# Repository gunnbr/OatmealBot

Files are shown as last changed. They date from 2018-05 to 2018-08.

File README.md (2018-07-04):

# OatmealBot
OatmealBot is a robot built on a circular platform using 3 [omni wheels](https://en.wikipedia.org/wiki/Omni_wheel) and
controlled using a PS3 controller. It's named OatmealBot because it was
originally designed so the control hardware could be hidden under a
cylindrical box of oatmeal.

## Features
This OatmealBot controller is built on top of the
[Adafruit Motor Hat](http://adafru.it/2348). This board provides the
following features on top of that:
* Powers the Hat and the Pi from a [Pololu 5V regulator](https://www.pololu.com/product/2858)
* Plug for 4
[Pololu motors with quadrature encoder](https://www.pololu.com/product/3240)
* Plugs for 3 servos
* 2 high power outputs
* Plug for [SPI OLED display](http://adafru.ti/938)
* 2 LED (status & error)
* Plug for
[FTDI TTL serial to USB adapter](http://www.ftdichip.com/Support/Documents/DataSheets/Cables/DS_TTL-232R_CABLES.pdf)

## History
This was initially envisioned using a SAMD21 controller so the motor
encoders could be read by hardware counters. However, I couldn't find
a good Bluetooth driver that worked. Although I found some existing
drivers that could be ported, I realized I could just as well get
a Raspberry Pi Zero W with built-in Bluetooth and a motor hat and
see how well it works without reading the encoders. Turns out it
worked fairly well, so I kept working down this path.

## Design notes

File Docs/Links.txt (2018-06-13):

http://www.societyofrobots.com/robot_omni_wheel.shtml

http://files.andymark.com/2008CON-Omni-Baker-McKenzie.pdf

http://basicrobot.blogspot.nl/2006/08/how-to-control-omni-direction-wheel.html

http://robotics.stackexchange.com/questions/7829/how-to-program-three-wheel-omni

http://stackoverflow.com/questions/3748037/how-to-control-a-kiwi-drive-robot

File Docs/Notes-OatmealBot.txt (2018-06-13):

To use a BT USB dongle with the Arduino Zero/Feather M0/SAMD21:
https://github.com/bluekitchen/btstack
Which is from:
http://bluekitchen-gmbh.com/
But it doesn't look like USB is very much supported. But maybe it is--it is referenced a few times.

Maybe port https://www.circuitsathome.com/category/mcu/arduino/usb-shield/ to the M0?
The latest version does support some native USB: https://github.com/felis/UHS30

Bluetooth spec:
https://www.bluetooth.com/specifications/bluetooth-core-specification

Atmel Studio contains an ASF example of a host vendor USB device. Looks like this is a template
for how a Bluetooth HCI class driver can be written.
Documentation about it is here: http://www.atmel.com/Images/Atmel-42336-ASF-USB-Stack-Manual_ApplicationNote_AT09331.pdf

Or port this, which is already for an embedded system and PS3 controller:
http://www.fourwalledcubicle.com/ExplorerBot.php
https://github.com/abcminiuser/explorerbot/tree/master/Code

New plan:
Run it from the Pi Zero.

From https://medium.com/home-wireless/headless-streaming-video-with-the-raspberry-pi-zero-w-and-raspberry-pi-camera-38bef1968e1
and https://github.com/cncjs/cncjs/wiki/Setup-Guide:-Raspberry-Pi-%7C-MJPEG-Streamer-Install-&-Setup-&-FFMpeg-Recording

To stream video from the Pi: 
mjpg_streamer -i "input_raspicam.so -x 1920 -y 1080" -o 'output_http.so -w ./www'

Then in a browser, go to:
http://10.0.0.37:8080/?action=stream

Article with the formulas:
https://stackoverflow.com/questions/3748037/how-to-control-a-kiwi-drive-robot

Gears in my kit: 2.00 mm inner diameter
Tower Pro micro server: 
	Inner diameter between 1.5 and 1.75 mm (designed for a screw)
	Outer diameter: 2.85 mm

Pi Adapter/control board: (22 total GPIO pins)
	Power in (easy to detach connector?)
	Voltage converter to 5V pin on Pi expansion header
	Headers to plug in the 4 motors with an easy way to connect them to the motor driver board and with A and B from the rotary encoder (8 GPIO lines)
	Headers for 4 servos (4 GPIO lines)
	SPI header for OLED display (5 GPIO)
	SPI header for other things (1 additional GPIO)
	LED indicators: (2 GPIO)
		1 neutral color indicate Bluetooth connection status
		1 red for error conditions
	
Adafruit Feature board that's similar

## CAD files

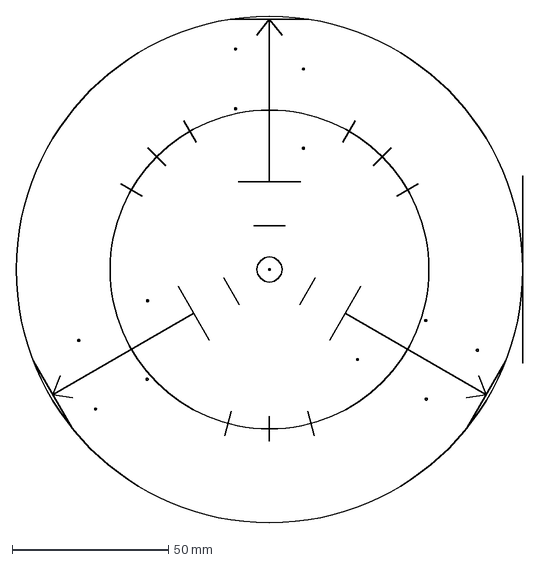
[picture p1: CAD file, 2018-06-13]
Mechanical/OutmealBotTemplate2.dxf
161.9 x 161.9 mm

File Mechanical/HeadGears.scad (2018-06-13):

//////////////////////////////////////////////////////////////////////////////////////////////
// Public Domain Parametric Involute Spur Gear (and involute helical gear and involute rack)
// version 1.1
// by Leemon Baird, 2011, Leemon@Leemon.com
//http://www.thingiverse.com/thing:5505
//
// This file is public domain.  Use it for any purpose, including commercial
// applications.  Attribution would be nice, but is not required.  There is
// no warranty of any kind, including its correctness, usefulness, or safety.
// 
// This is parameterized involute spur (or helical) gear.  It is much simpler and less powerful than
// others on Thingiverse.  But it is public domain.  I implemented it from scratch from the 
// descriptions and equations on Wikipedia and the web, using Mathematica for calculations and testing,
// and I now release it into the public domain.
//
//		http://en.wikipedia.org/wiki/Involute_gear
//		http://en.wikipedia.org/wiki/Gear
//		http://en.wikipedia.org/wiki/List_of_gear_nomenclature
//		http://gtrebaol.free.fr/doc/catia/spur_gear.html
//		http://www.cs.cmu.edu/~rapidproto/mechanisms/chpt7.html
//
// The module gear() gives an involute spur gear, with reasonable defaults for all the parameters.
// Normally, you should just choose the first 4 parameters, and let the rest be default values.
// The module gear() gives a gear in the XY plane, centered on the origin, with one tooth centered on
// the positive Y axis.  The various functions below it take the same parameters, and return various
// measurements for the gear.  The most important is pitch_radius, which tells how far apart to space
// gears that are meshing, and adendum_radius, which gives the size of the region filled by the gear.
// A gear has a "pitch circle", which is an invisible circle that cuts through the middle of each
// tooth (though not the exact center). In order for two gears to mesh, their pitch circles should 
// just touch.  So the distance between their centers should be pitch_radius() for one, plus pitch_radius() 
// for the other, which gives the radii of their pitch circles.
//
// In order for two gears to mesh, they must have the same mm_per_tooth and pressure_angle parameters.  
// mm_per_tooth gives the number of millimeters of arc around the pitch circle covered by one tooth and one
// space between teeth.  The pitch angle controls how flat or bulged the sides of the teeth are.  Common
// values include 14.5 degrees and 20 degrees, and occasionally 25.  Though I've seen 28 recommended for
// plastic gears. Larger numbers bulge out more, giving stronger teeth, so 28 degrees is the default here.
//
// The ratio of number_of_teeth for two meshing gears gives how many times one will make a full 
// revolution when the the other makes one full revolution.  If the two numbers are coprime (i.e. 
// are not both divisible by the same number greater than 1), then every tooth on one gear
// will meet every tooth on the other, for more even wear.  So coprime numbers of teeth are good.
//
// The module rack() gives a rack, which is a bar with teeth.  A rack can mesh with any
// gear that has the same mm_per_tooth and pressure_angle.
//
// Some terminology: 
// The outline of a gear is a smooth circle (the "pitch circle") which has mountains and valleys
// added so it is toothed.  So there is an inner circle (the "root circle") that touches the 
// base of all the teeth, an outer circle that touches the tips of all the teeth,
// and the invisible pitch circle in between them.  There is also a "base circle", which can be smaller than
// all three of the others, which controls the shape of the teeth.  The side of each tooth lies on the path 
// that the end of a string would follow if it were wrapped tightly around the base circle, then slowly unwound.  
// That shape is an "involute", which gives this type of gear its name.
//
//////////////////////////////////////////////////////////////////////////////////////////////

//An involute spur gear, with reasonable defaults for all the parameters.
//Normally, you should just choose the first 4 parameters, and let the rest be default values.
//Meshing gears must match in mm_per_tooth, pressure_angle, and twist,
//and be separated by the sum of their pitch radii, which can be found with pitch_radius().
module gear (
	mm_per_tooth    = 3,    //this is the "circular pitch", the circumference of the pitch circle divided by the number of teeth
	number_of_teeth = 11,   //total number of teeth around the entire perimeter
	thickness       = 6,    //thickness of gear in mm
	hole_diameter   = 3,    //diameter of the hole in the center, in mm
	twist           = 0,    //teeth rotate this many degrees from bottom of gear to top.  360 makes the gear a screw with each thread going around once
	teeth_to_hide   = 0,    //number of teeth to delete to make this only a fraction of a circle
	pressure_angle  = 28,   //Controls how straight or bulged the tooth sides are. In degrees.
	clearance       = 0.0,  //gap between top of a tooth on one gear and bottom of valley on a meshing gear (in millimeters)
	backlash        = 0.0   //gap between two meshing teeth, in the direction along the circumference of the pitch circle
) {
	assign(pi = 3.1415926)
	assign(p  = mm_per_tooth * number_of_teeth / pi / 2)  //radius of pitch circle
	assign(c  = p + mm_per_tooth / pi - clearance)        //radius of outer circle
	assign(b  = p*cos(pressure_angle))                    //radius of base circle
	assign(r  = p-(c-p)-clearance)                        //radius of root circle
	assign(t  = mm_per_tooth/2-backlash/2)                //tooth thickness at pitch circle
	assign(k  = -iang(b, p) - t/2/p/pi*180) {             //angle to where involute meets base circle on each side of tooth
		difference() {
			for (i = [0:number_of_teeth-teeth_to_hide-1] )
				rotate([0,0,i*360/number_of_teeth])
					linear_extrude(height = thickness, center = true, convexity = 10, twist = twist)
						polygon(
							points=[
								[0, -hole_diameter/10],
								polar(r, -181/number_of_teeth),
								polar(r, r<b ? k : -180/number_of_teeth),
								q7(0/5,r,b,c,k, 1),q7(1/5,r,b,c,k, 1),q7(2/5,r,b,c,k, 1),q7(3/5,r,b,c,k, 1),q7(4/5,r,b,c,k, 1),q7(5/5,r,b,c,k, 1),
								q7(5/5,r,b,c,k,-1),q7(4/5,r,b,c,k,-1),q7(3/5,r,b,c,k,-1),q7(2/5,r,b,c,k,-1),q7(1/5,r,b,c,k,-1),q7(0/5,r,b,c,k,-1),
								polar(r, r<b ? -k : 180/number_of_teeth),
								polar(r, 181/number_of_teeth)
							],
 							paths=[[0,1,2,3,4,5,6,7,8,9,10,11,12,13,14,15,16]]
						);
			cylinder(h=2*thickness+1, r=hole_diameter/2, center=true, $fn=20);
		}
	}
};	
//these 4 functions are used by gear
function polar(r,theta)   = r*[sin(theta), cos(theta)];                            //convert polar to cartesian coordinates
function iang(r1,r2)      = sqrt((r2/r1)*(r2/r1) - 1)/3.1415926*180 - acos(r1/r2); //unwind a string this many degrees to go from radius r1 to radius r2
function q7(f,r,b,r2,t,s) = q6(b,s,t,(1-f)*max(b,r)+f*r2);                         //radius a fraction f up the curved side of the tooth 
function q6(b,s,t,d)      = polar(d,s*(iang(b,d)+t));                              //point at radius d on the involute curve

//a rack, which is a straight line with teeth (the same as a segment from a giant gear with a huge number of teeth).
//The "pitch circle" is a line along the X axis.
module rack (
	mm_per_tooth    = 3,    //this is the "circular pitch", the circumference of the pitch circle divided by the number of teeth
	number_of_teeth = 11,   //total number of teeth along the rack
	thickness       = 6,    //thickness of rack in mm (affects each tooth)
	height          = 120,   //height of rack in mm, from tooth top to far side of rack.
	pressure_angle  = 28,   //Controls how straight or bulged the tooth sides are. In degrees.
	backlash        = 0.0   //gap between two meshing teeth, in the direction along the circumference of the pitch circle
) {
	assign(pi = 3.1415926)
	assign(a = mm_per_tooth / pi) //addendum
	assign(t = a*cos(pressure_angle)-1)         //tooth side is tilted so top/bottom corners move this amount
		for (i = [0:number_of_teeth-1] )
			translate([i*mm_per_tooth,0,0])
				linear_extrude(height = thickness, center = true, convexity = 10)
					polygon(
						points=[
							[-mm_per_tooth * 3/4,                 a-height],
							[-mm_per_tooth * 3/4 - backlash,     -a],
							[-mm_per_tooth * 1/4 + backlash - t, -a],
							[-mm_per_tooth * 1/4 + backlash + t,  a],
							[ mm_per_tooth * 1/4 - backlash - t,  a],
							[ mm_per_tooth * 1/4 - backlash + t, -a],
							[ mm_per_tooth * 3/4 + backlash,     -a],
							[ mm_per_tooth * 3/4,                 a-height],
						],
						paths=[[0,1,2,3,4,5,6,7]]
					);
};
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

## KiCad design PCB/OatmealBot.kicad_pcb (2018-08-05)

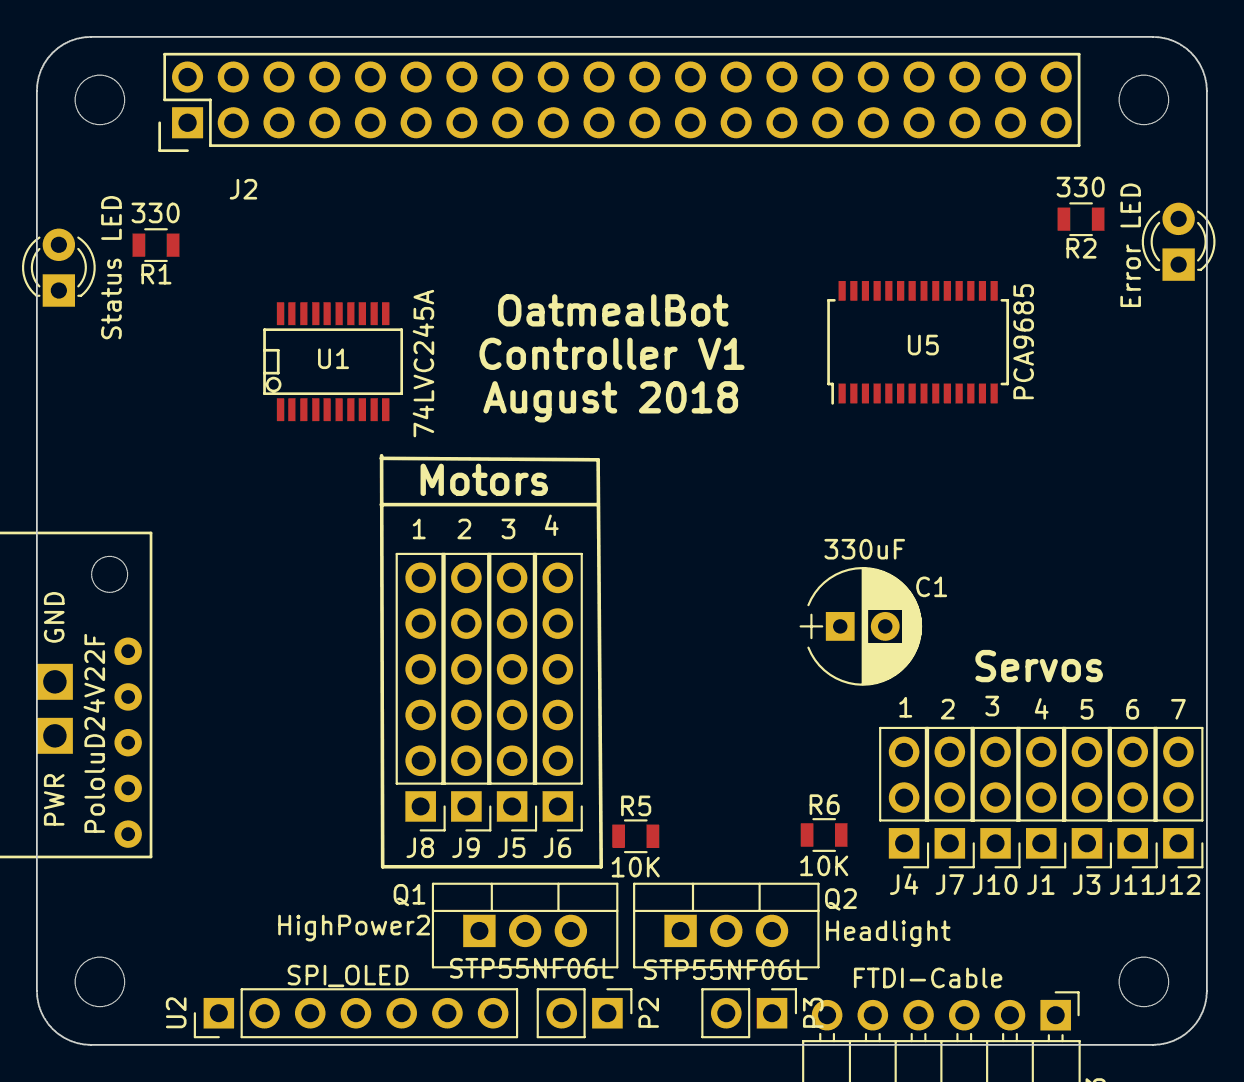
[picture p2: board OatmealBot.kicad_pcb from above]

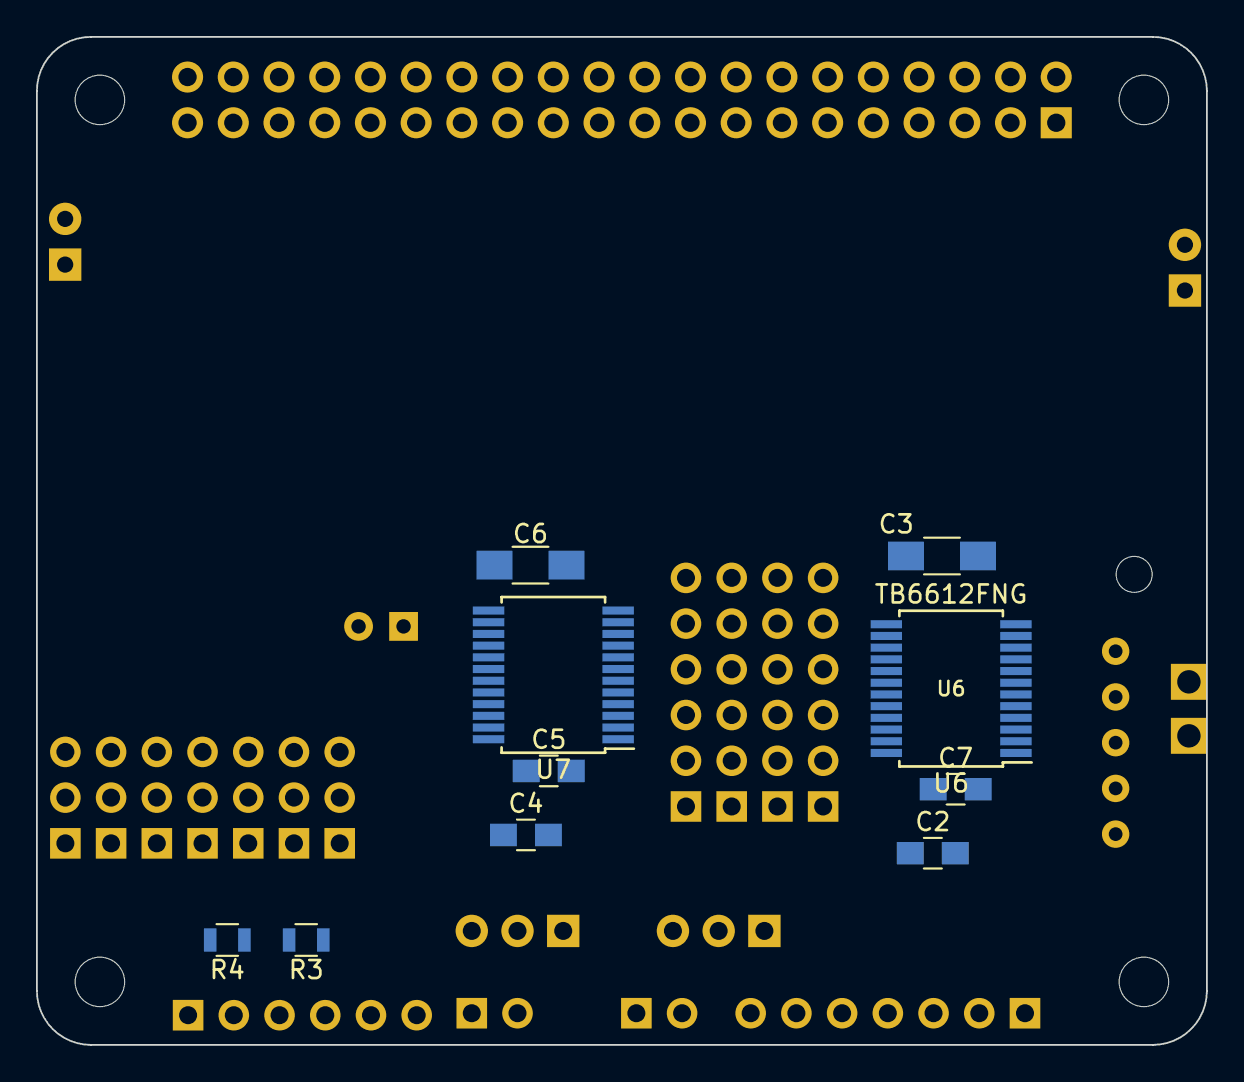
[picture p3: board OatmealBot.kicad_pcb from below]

Board: 2 copper layers, 65.0 x 56.0 mm, 39 parts (10 on the bottom side), 65 nets, no tracks yet.

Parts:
C1: 330uF; CP_Radial_D6.3mm_P2.50mm
C2, C4: 10uF; C_0805_HandSoldering
C3, C6: 47uF; C_1206_HandSoldering
C5, C7: 0.1uF; C_0805_HandSoldering
D1: Status LED; LED_D3.0mm
D2: Error LED; LED_D3.0mm
J1: 4; Pin_Header_Straight_1x03_Pitch2.54mm
J2: RPi_GPIO; Pin_Header_Straight_2x20
J3: 5; Pin_Header_Straight_1x03_Pitch2.54mm
J4: 1; Pin_Header_Straight_1x03_Pitch2.54mm
J5: 3; Pin_Header_Straight_1x06_Pitch2.54mm
J6: 4; Pin_Header_Straight_1x06_Pitch2.54mm
J7: 2; Pin_Header_Straight_1x03_Pitch2.54mm
J8: 1; Pin_Header_Straight_1x06_Pitch2.54mm
J9: 2; Pin_Header_Straight_1x06_Pitch2.54mm
J10: 3; Pin_Header_Straight_1x03_Pitch2.54mm
J11: 6; Pin_Header_Straight_1x03_Pitch2.54mm
J12: 7; Pin_Header_Straight_1x03_Pitch2.54mm
P1: Motor Hat Power; Power_Connector_Soldered
P2: HighPower2; Pin_Header_Straight_1x02_Pitch2.54mm
P3: Headlight; Pin_Header_Straight_1x02_Pitch2.54mm
Q1, Q2: STP55NF06L; TO-220-3_Vertical
R1, R2: 330; R_0805
R3, R4: R; R_0805
R5, R6: 10K; R_0805
U1: 74LVC245A; SSOP-20
U2: SPI_OLED; Socket_Strip_Straight_1x07_Pitch2.54mm
U3: FTDI-Cable; Pin_Header_Angled_1x06_Pitch2.54mm
U4: PololuD24V22F
U5: PCA9685; TSSOP-28_4.4x9.7mm_Pitch0.65mm
U6, U7: TB6612FNG; SSOP-24_5.3x8.2mm_Pitch0.65mm

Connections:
+3V3: C2.1, C4.1, C5.1, C7.1, J2.1, J2.17, U1.1, U1.20, U2.2, U5.24, U5.28, U6.19, U6.20, U7.19, U7.20
+5V: C1.1, J1.2, J2.2, J2.4, J3.2, J4.2, J5.4, J6.4, J7.2, J8.4, J9.4, J10.2, J11.2, J12.2, U4.5
+12V: C3.1, C6.1, P1.2, U4.3, U6.13, U6.14, U6.24, U7.13, U7.14, U7.24
/MotorController/Motor1+: J8.1, U6.1, U6.2
/MotorController/Motor1-: J8.2, U6.5, U6.6
/MotorController/Motor2+: J9.1, U6.7, U6.8
/MotorController/Motor2-: J9.2, U6.11, U6.12
/MotorController/Motor3+: J5.1, U7.1, U7.2
/MotorController/Motor3-: J5.2, U7.5, U7.6
/MotorController/Motor4+: J6.1, U7.7, U7.8
/MotorController/Motor4-: J6.2, U7.11, U7.12
ENC1A: J2.40, U1.17
ENC1B: J2.38, U1.18
ENC2A: J2.36, U1.15
ENC2B: J2.37, U1.16
ENC3A: J2.33, U1.13
ENC3B: J2.35, U1.14
ENC4A: J2.31, U1.11
ENC4B: J2.29, U1.12
GND: C1.2, C2.2, C3.2, C4.2, C5.2, C6.2, C7.2, D1.1, D2.1, J1.1, J2.6, J2.9, J2.14, J2.20, J2.25, J2.30, J2.34, J2.39, J3.1, J4.1, J5.3, J6.3, J7.1, J8.3, J9.3, J10.1, J11.1, J12.1, P1.1, P2.1, P3.1, Q1.3, Q2.3, R4.2, R5.2, R6.2, U1.10, U1.19, U2.1, U3.1, U4.4, U5.1, U5.2, U5.3, U5.4, U5.5, U5.14, U5.23, U5.25, U6.3, U6.4, U6.9, U6.10, U6.18, U7.3, U7.4, U7.9, U7.10, U7.18
Headlight: J2.7, Q2.1, R6.1
HighPower2: J2.13, Q1.1, R5.1
MOSI: J2.19, U2.4
unnamed: D1.2, R1.2
unnamed: D2.2, R2.1
unnamed: J2.15, R1.1
unnamed: J2.16, R2.2
unnamed: J5.5, U1.7
unnamed: J5.6, U1.6
unnamed: J6.5, U1.9
unnamed: J6.6, U1.8
unnamed: J8.5, U1.3
unnamed: J8.6, U1.2
unnamed: J9.5, U1.5
unnamed: J9.6, U1.4
unnamed: P2.2, Q1.2
unnamed: P3.2, Q2.2
unnamed: R3.1, U3.4
unnamed: U5.8, U6.23
unnamed: U5.9, U6.22
unnamed: U5.10, U6.21
unnamed: U5.11, U6.17
unnamed: U5.12, U6.16
unnamed: U5.13, U6.15
unnamed: U5.15, U7.23
unnamed: U5.16, U7.22
unnamed: U5.17, U7.21
unnamed: U5.18, U7.17
unnamed: U5.19, U7.16
unnamed: U5.20, U7.15
OLED_CS: J2.24, U2.7
OLED_DC: J2.22, U2.6
OLED_RESET: J2.18, U2.5
PI_RXD: J2.10, R3.2, R4.1
PI_TXD: J2.8, U3.5
SCL: J2.5, U5.26
SCLK: J2.23, U2.3
SDA: J2.3, U5.27
Servo1: J2.32, J4.3
Servo2: J2.12, J7.3
Servo3: J2.11, J10.3
Servo4: J1.3, U5.6
Servo5: J3.3, U5.7
Servo6: J11.3, U5.21
Servo7: J12.3, U5.22

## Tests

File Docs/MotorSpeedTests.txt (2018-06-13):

100 ms per line

TCNT: 20
TCNT: 22
TCNT: 22
TCNT: 21
TCNT: 22
TCNT: 22
TCNT: 21
TCNT: 22
TCNT: 22
TCNT: 21
TCNT: 22
TCNT: 22
TCNT: 21
TCNT: 22
TCNT: 22
TCNT: 21
TCNT: 21
TCNT: 22
TCNT: 22
TCNT: 21
TCNT: 22
TCNT: 22
TCNT: 22
TCNT: 21
TCNT: 22
TCNT: 22
TCNT: 21
TCNT: 22
TCNT: 22
TCNT: 21
TCNT: 22
TCNT: 22
TCNT: 21
Speed: 255
TCNT: 46
TCNT: 102
TCNT: 106
TCNT: 107
TCNT: 106
TCNT: 107
TCNT: 107
TCNT: 106
TCNT: 107
TCNT: 107
TCNT: 107
TCNT: 107
TCNT: 107
TCNT: 107
TCNT: 107
TCNT: 107
TCNT: 106
TCNT: 107
TCNT: 107
TCNT: 107
Speed: 10
TCNT: 85
TCNT: 7
TCNT: 1
TCNT: 3
TCNT: 1
TCNT: 2
TCNT: 1
TCNT: 2
TCNT: 3
TCNT: 2
TCNT: 3
TCNT: 2
TCNT: 3
TCNT: 2
TCNT: 3
TCNT: 2
TCNT: 2
TCNT: 3
TCNT: 2
TCNT: 3
TCNT: 2
Speed: 255
TCNT: 69
TCNT: 105
TCNT: 107
TCNT: 107
TCNT: 107
TCNT: 107
TCNT: 107
TCNT: 107
TCNT: 107
TCNT: 107
TCNT: 107
TCNT: 107
TCNT: 107
TCNT: 108
TCNT: 107
TCNT: 107
TCNT: 107
TCNT: 107
TCNT: 107
TCNT: 107
Speed: 10
TCNT: 106
TCNT: 22
TCNT: 2
TCNT: 2
TCNT: 2
TCNT: 2
TCNT: 1
TCNT: 1
TCNT: 3
TCNT: 3
TCNT: 2
TCNT: 3
TCNT: 2
TCNT: 3
TCNT: 2
TCNT: 3
TCNT: 2
Speed: 128
TCNT: 38
TCNT: 53
TCNT: 53
TCNT: 53
TCNT: 53
TCNT: 53
TCNT: 53
TCNT: 52
TCNT: 53
TCNT: 53
TCNT: 53
TCNT: 53
TCNT: 53
Speed: 10
TCNT: 34
TCNT: 3
TCNT: 3
TCNT: 3
TCNT: 2
TCNT: 2
TCNT: 3
TCNT: 3
TCNT: 2
TCNT: 3
TCNT: 2
TCNT: 3
TCNT: 2
TCNT: 3
TCNT: 3
TCNT: 2
Speed: 128
TCNT: 33
TCNT: 52
TCNT: 53
TCNT: 53
TCNT: 53
TCNT: 53
TCNT: 53
TCNT: 53
TCNT: 53
TCNT: 53
TCNT: 52
TCNT: 53
TCNT: 53
TCNT: 53
TCNT: 53
TCNT: 53
TCNT: 53
TCNT: 53
Speed: 10
TCNT: 22
TCNT: 2
TCNT: 3
TCNT: 2
TCNT: 3
TCNT: 2
TCNT: 2
TCNT: 3
TCNT: 2
TCNT: 3
TCNT: 2
TCNT: 3
TCNT: 2
Speed: 128
TCNT: 28
TCNT: 53
TCNT: 53
TCNT: 53
TCNT: 53
TCNT: 53
TCNT: 53
TCNT: 52
TCNT: 53
TCNT: 53
TCNT: 53
TCNT: 53
TCNT: 53
TCNT: 53
TCNT: 53
Speed: 255
TCNT: 73
TCNT: 105
TCNT: 107
TCNT: 107
TCNT: 106
TCNT: 108
TCNT: 107
TCNT: 107
TCNT: 107
TCNT: 107
TCNT: 108
TCNT: 107
TCNT: 107
TCNT: 107
TCNT: 107
Speed: 128
TCNT: 100
TCNT: 59
TCNT: 49
TCNT: 43
TCNT: 38
TCNT: 32
TCNT: 37
TCNT: 52
TCNT: 53
TCNT: 53
TCNT: 53
TCNT: 53
TCNT: 53
TCNT: 53
TCNT: 53
TCNT: 54
TCNT: 52
TCNT: 53
TCNT: 53
TCNT: 53
TCNT: 53
TCNT: 54
TCNT: 53
Speed: 255
TCNT: 55
TCNT: 98
TCNT: 107
TCNT: 107
TCNT: 107
TCNT: 108
TCNT: 107
TCNT: 107
TCNT: 108
TCNT: 107
TCNT: 107
TCNT: 108
TCNT: 107
TCNT: 107
Speed: 128
TCNT: 99
TCNT: 58
TCNT: 49
TCNT: 43
TCNT: 37
TCNT: 33
TCNT: 37
TCNT: 53
TCNT: 53
TCNT: 53
TCNT: 53
TCNT: 54
TCNT: 53
TCNT: 53
TCNT: 53
TCNT: 53
TCNT: 53
TCNT: 53
TCNT: 54
TCNT: 53
TCNT: 53
Speed: 255
TCNT: 85
TCNT: 106
TCNT: 108
TCNT: 107
TCNT: 107
TCNT: 108
TCNT: 107
TCNT: 108
TCNT: 107
TCNT: 108
Speed: 128
TCNT: 92
TCNT: 56
TCNT: 48
TCNT: 42
TCNT: 37 <-- Strange dip below the target value when going from full to half speed
TCNT: 32
TCNT: 42
TCNT: 53 <-- 800 ms until target speed
TCNT: 53
TCNT: 53
TCNT: 53
TCNT: 53
TCNT: 53
TCNT: 54
TCNT: 53
TCNT: 53
TCNT: 53
TCNT: 54
TCNT: 53
TCNT: 53
TCNT: 53
TCNT: 53
TCNT: 53
TCNT: 53
TCNT: 54
TCNT: 53
TCNT: 53
TCNT: 53
TCNT: 53
TCNT: 53
TCNT: 54
TCNT: 53
TCNT: 53
TCNT: 53
TCNT: 53
TCNT: 53
TCNT: 53
TCNT: 54
TCNT: 53
TCNT: 53
TCNT: 53
TCNT: 53
TCNT: 53
TCNT: 54
TCNT: 53
TCNT: 53
TCNT: 53
TCNT: 53
T

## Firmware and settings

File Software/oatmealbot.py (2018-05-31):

#!/usr/bin/python

import os, struct, array, time, sys
import threading
from fcntl import ioctl
import pigpio
import atexit
import math
import translatemotoroutputs
from Adafruit_MotorHAT import Adafruit_MotorHAT, Adafruit_DCMotor

debug = False

pi = pigpio.pi()

joyfn = '/dev/input/js0'
jsdev = -1
LED_PIN = 26

# We'll store the button states here.
axis_states = {}
button_states = {}

# Create the MotorHat object using default settings,
# no changes to I2C address or frequency
mh = Adafruit_MotorHAT(addr=0x60)

exiting = False

def emergencyShutdown():
    global exiting
    
    exiting = True
    # Full stop on all the motors
    mh.getMotor(1).run(Adafruit_MotorHAT.RELEASE)
    mh.getMotor(2).run(Adafruit_MotorHAT.RELEASE)
    mh.getMotor(3).run(Adafruit_MotorHAT.RELEASE)
    mh.getMotor(4).run(Adafruit_MotorHAT.RELEASE)

    pi.wave_tx_stop()
    error_flash = []
    error_flash.append(pigpio.pulse(1<<LED_PIN,    0, 100000))
    error_flash.append(pigpio.pulse(0,    1<<LED_PIN, 100000))
    error_flash.append(pigpio.pulse(1<<LED_PIN,    0, 100000))
    error_flash.append(pigpio.pulse(0,    1<<LED_PIN, 100000))
    error_flash.append(pigpio.pulse(1<<LED_PIN,    0, 100000))
    error_flash.append(pigpio.pulse(0,    1<<LED_PIN, 1000000))
    pi.wave_clear() # clear any existing waveforms
    pi.wave_add_generic(error_flash)
    errorFlash = pi.wave_create() # create and save id
    pi.wave_send_repeat(errorFlash)
    
atexit.register(emergencyShutdown)

# These constants were borrowed from linux/input.h
axis_names = {
    0x00 : 'x',
    0x01 : 'y',
    0x02 : 'z',
    0x03 : 'rx',
    0x04 : 'ry',
    0x05 : 'rz',
    0x06 : 'trottle',
    0x07 : 'rudder',
    0x08 : 'wheel',
    0x09 : 'gas',
    0x0a : 'brake',
    0x10 : 'hat0x',
    0x11 : 'hat0y',
    0x12 : 'hat1x',
    0x13 : 'hat1y',
    0x14 : 'hat2x',
    0x15 : 'hat2y',
    0x16 : 'hat3x',
    0x17 : 'hat3y',
    0x18 : 'pressure',
    0x19 : 'distance',
    0x1a : 'tilt_x',
    0x1b : 'tilt_y',
    0x1c : 'tool_width',
    0x20 : 'volume',
    0x28 : 'misc',
    0x2c : 'dpad up',  # ps3
    0x2d : 'dpad right',  # ps3
    0x2e : 'dpad down',  # ps3
    0x2f : 'dpad left',  # ps3
    0x30 : 'left trigger',  # ps3
    0x31 : 'right trigger', # ps3
    0x32 : 'left shoulder',  # ps3
    0x33 : 'right shoulder',  # ps3
    0x34 : 'triangle',  # ps3
    0x35 : 'circle',   # ps3
    0x36 : 'x',   # ps3
    0x37 : 'square',   # ps3
}

button_names = {
    0x120 : 'menu', # ps3
    0x121 : 'left thumb', # ps3
    0x122 : 'right thumb', # ps3
    0x123 : 'start', # ps3
    0x124 : 'dpad up', # ps3
    0x125 : 'dpad right', # ps3
    0x126 : 'dpad down', # ps3
    0x127 : 'dpad left', # ps3
    0x128 : 'left trigger', # ps3
    0x129 : 'right trigger', # ps3
    0x12a : 'left shoulder', # ps3
    0x12b : 'right shoulder', # ps3
    0x12c : 'triangle',  # ps3
    0x12d : 'circle', # ps3
    0x12e : 'x', # ps3
    0x12f : 'square', # ps3
    0x130 : 'a',
    0x131 : 'b',
    0x132 : 'c',
    0x133 : 'x',
    0x134 : 'y',
    0x135 : 'z',
    0x136 : 'tl',
    0x137 : 'tr',
    0x138 : 'tl2',
    0x139 : 'tr2',
    0x13a : 'select',
    0x13b : 'start',
    0x13c : 'mode',
    0x13d : 'thumbl',
    0x13e : 'thumbr',

    0x220 : 'dpad_up',
    0x221 : 'dpad_down',
    0x222 : 'PlayStation', # ps3
    0x223 : 'dpad_right',

    # XBox 360 controller uses these codes.
    0x2c0 : 'dpad_left',
    0x2c1 : 'dpad_right',
    0x2c2 : 'dpad_up',
    0x2c3 : 'dpad_down',
}

axis_map = []
button_map = []

joy_x = 0
joy_y = 0
joy_r = 0

class MotionControlThread (threading.Thread):
    def __init__(self):
        threading.Thread.__init__(self)
    def run(self):
        global exiting, debug, joy_x, joy_y, joy_r
        while not exiting:
            outputs = translatemotoroutputs.translate(joy_x, joy_y, joy_r)

            #if debug:
                #print ("M1 {:>6.0f} M2 {:>6.0f} M3 {:>6.0f}".format(outputs.m1, outputs.m2, outputs.m3))

            m1 = mh.getMotor(1)
            m2 = mh.getMotor(2)
            m3 = mh.getMotor(3)
            
            m1.setSpeed(int(abs(outputs.m1)))
            if outputs.m1 < 0:
                m1.run(Adafruit_MotorHAT.BACKWARD)
            else:
                m1.run(Adafruit_MotorHAT.FORWARD)
            
            m2.setSpeed(int(abs(outputs.m2)))
            if outputs.m2 < 0:
                m2.run(Adafruit_MotorHAT.BACKWARD)
            else:
                m2.run(Adafruit_MotorHAT.FORWARD)
            
            m3.setSpeed(int(abs(outputs.m3)))
            if outputs.m3 < 0:
                m3.run(Adafruit_MotorHAT.BACKWARD)
            else:
                m3.run(Adafruit_MotorHAT.FORWARD)
    
def connectJoystick():
    global joyfn, jsdev, axis_names, pi
    led_status = 1
    print('Opening %s...' % joyfn)
    while jsdev == -1:
        try:
            pi.write(LED_PIN, led_status)
            led_status = 0 if led_status else 1
            jsdev = open(joyfn, 'rb')

            buf = array.array('c', ['\0'] * 64)
            ioctl(jsdev, 0x80006a13 + (0x10000 * len(buf)), buf) # JSIOCGNAME(len)
            js_name = buf.tostring()
            print('Device name: %s' % js_name)

            # Get number of axes and buttons.
            buf = array.array('B', [0])
            ioctl(jsdev, 0x80016a11, buf) # JSIOCGAXES
            num_axes = buf[0]

            buf = array.array('B', [0])
            ioctl(jsdev, 0x80016a12, buf) # JSIOCGBUTTONS
            num_buttons = buf[0]

            # Get the axis map.
            buf = array.array('B', [0] * 0x40)
            ioctl(jsdev, 0x80406a32, buf) # JSIOCGAXMAP

            for axis in buf[:num_axes]:
                axis_name = axis_names.get(axis, 'unknown_axis(0x%02x)' % axis)
                axis_map.append(axis_name)
                axis_states[axis_name] = 0.0

            # Get the button map.
            buf = array.array('H', [0] * 200)
            ioctl(jsdev, 0x80406a34, buf) # JSIOCGBTNMAP

            for btn in buf[:num_buttons]:
                btn_name = button_names.get(btn, 'unknown_button(0x%03x)' % btn)
                button_map.append(btn_name)
                button_states[btn_name] = 0

            print '%d axes found.' % num_axes
            print '%d buttons found.' % num_buttons
            
        except IOError:
            if jsdev != -1:
                close(jsdev)
                jsdev = -1

            print('Joystick not connected. Waiting...')
            time.sleep(1)

def readJoysticks():
    global jsdev, joy_x, joy_y, joy_r
    evbuf = jsdev.read(8)
    if evbuf:
        time, value, type, number = struct.unpack('IhBB', evbuf)
        #print ("Type: 0x{:02x} Number: 0x{:02x} Value: {:d}".format(type,number,value))
               
        if type & 0x80: # JS_EVENT_INIT
            return
            #print "(initial)",

        if type & 0x01: # JS_EVENT_BUTTON
            button = button_map[number]
            if button:
                button_states[button] = value
                if debug:
                    if value:
                        print "%s pressed" % (button)
                    else:
                        print "%s released" % (button)
            elif debug:
                print "Unknown button 0x%x event" % (button)

        if type & 0x02: # JS_EVENT_AXIS

            # Ignore the accelerometer axes
            if number == 0x19 or number == 0x17 or number == 0x1a or number == 0x18:
                return

            # In fact, ignore all the axes except for the 3 we care about right now
            if number != 0 and number != 1 and number != 2:
                return
            
            #print "axis 0x{:02x}".format(number)
            axis = axis_map[number]
            if not axis:
                return
            
            # Value returned is the range -32767 to 32767
            # Convert to -255 to 255 by dividing by 128.5
            fvalue = value / 128.5
            axis_states[axis] = fvalue
            #print "%s: %.3f" % (axis, fvalue)
            joy_x = axis_states["x"]
            joy_y = axis_states["y"]
            joy_r = axis_states["z"]
            if debug:
                print (" X {:>6.3f}  Y {:>6.3f}  R {:>6.3f}".format(axis_states["x"],
                                                                    axis_states["y"],
                                                                    axis_states["z"]))
    
def main():
    global jsdev,debug,mh, exiting

    if len(sys.argv) > 1 and sys.argv[1] == "quiet":
        debug = False

    pi.set_mode(LED_PIN, pigpio.OUTPUT)

    
    # 100 ms flash once every 2 seconds to indicate connection
    happy_flash = []
    happy_flash.append(pigpio.pulse(1<<LED_PIN,    0, 100000))
    happy_flash.append(pigpio.pulse(0,    1<<LED_PIN, 2000000))
    pi.wave_clear() # clear any existing waveforms
    pi.wave_add_generic(happy_flash)
    happyFlash = pi.wave_create() # create and save id

    controlThread = MotionControlThread()

    controlThread.start()
    
    while not exiting:
        try:
            pi.wave_tx_stop()
        
            connectJoystick()

            pi.wave_send_repeat(happyFlash)
            error = False
            while not error:
                try:
                    readJoysticks()
                except IOError:
                    error = True;
                    jsdev = -1
        except KeyboardInterrupt:
            print "Got keyboard interrupt. Exiting..."
            exiting = True
    print "Done looping"
                
if __name__ == "__main__":
    print "OatmealBox starting..."
    main()

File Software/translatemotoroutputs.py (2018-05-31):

# Here, as per https://stackoverflow.com/questions/3748037/how-to-control-a-kiwi-drive-robot,
# we define motor 3 (M3) as the X direction and M1 and M2 in the offset Y direction.
import math
import collections

def translate(x, y, r):
    """Translate x, y, and rotation inputs to motor 1, motor 2, motor 3 outputs.

       X, Y, and R are in the range of -255 to 255.
       M1, M2, and M3 are in the range of -255 to 255.
    """
    Y_MULTIPLIER = math.sqrt(3) / 2

    #print "   Input--  X: {0:3.0f}   Y: {1:3.0f}   R: {2:3.0f}".format(x,y,r)
    m1 = -x/2 - Y_MULTIPLIER * y - r
    m2 = -x/2 + Y_MULTIPLIER * y - r
    m3 = x - r
    #print "Unscaled-- M1: {0:3.0f}  M2: {1:3.0f}  M3: {2:3.0f}".format(m1, m2, m3)
    maximum = max([m1,m2,m3])
    minimum = min([m1,m2,m3])
    if abs(minimum) > maximum:
        maximum = abs(minimum)
    if maximum > 255:
        scale_factor = 255.0 / maximum
        #print "Maximum is {0:3.0f} Scale factor is {1:3.3f}".format(maximum,scale_factor)
        m1 = m1 * scale_factor
        m2 = m2 * scale_factor
        m3 = m3 * scale_factor
        #print "**Scaled-- M1: {0:3.0f}  M2: {1:3.0f}  M3: {2:3.0f}".format(m1, m2, m3)
    MotorOutputs = collections.namedtuple('MotorOutputs', ['m1', 'm2', 'm3'])
    return MotorOutputs(m1,m2,m3)

#print(timeit.timeit("TranslateMotorOutputs(255,0,255)", number=1000, setup="from __main__ import TranslateMotorOutputs"))

if __name__ == "__main__":
    print "TranslateMotorOutputs is running"

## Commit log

2018-05-31 Initial re-implementation of oatmealbot using pigpio instead of relying on pygame. Added status indicator LED. Doesn't actually control the motors.
    [oatmealbot.py, translatemotoroutputs.py]
2018-05-31 Added support for driving the motors. Now works better than the old pygame version since it is able to start at boot! (And also provides the status LED.)
2018-06-13 Added docs, mechanical design, and PCB design.
    [HeadGears.scad, OatmealBot.kicad_pcb, OatmealBot.sch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]
2018-06-16 Added 5V to 3.3V level shifter on the encoder outputs. Hooked up all encoder outputs.
    [OatmealBot.sch]
2018-06-16 Added LEDs and servo connectors
    [OatmealBot.sch]
2018-06-19 Added power connectors
    [OatmealBot.sch]
2018-06-20 Added serial port connector
    [OatmealBot.sch]
2018-06-20 Added OLED SPI connector
    [OatmealBot.sch]
2018-06-22 Hooked up the servo outputs correctly. Fixed a lot of design rule problems.
    [OatmealBot.sch]
2018-06-22 Started assigning some footprints. Initial PCB layout.
    [OatmealBot.kicad_pcb, OatmealBot.sch]
2018-06-30 Added MOSFET for headlight
    [OatmealBot.sch]
2018-07-01 Added second high power connector
    [OatmealBot.sch]
2018-07-04 Updated README with more details about exactly what the board does.
2018-07-04 Fixed spelling of OatmealBot (facepalm) and added link for omni wheel.
2018-07-04 Fixed PCB edges to connect properly. Removed extra explanation text about selecting the right footprint. Attempted to fix 3D models, but it hasn't worked right.
    [OatmealBot.kicad_pcb]
2018-07-05 Fixed some of the 3D models. SPI_OLED and the Pololu power connector still aren't lined up properly though.
    [OatmealBot.kicad_pcb, OatmealBot.sch]
2018-07-05 Fixed placement of 3D model for Pololu power and SPI_OLED.
    [OatmealBot.kicad_pcb]
2018-07-05 Updated to KiCad 4.0.7 (which lost the 3D models I had just gotten working) Assigned more footprints.
    [OatmealBot.kicad_pcb, OatmealBot.sch]
2018-07-06 Created proper footprint for the voltage regulator so it's easier to see how much space it takes up on the board. Changed the board layout to fit the regulator. Fixed some more 3D files
    [OatmealBot.kicad_pcb, OatmealBot.sch]
2018-07-13 Added 4 more servo headers for the extra PWM outputs. Rearranged the schematic a little to fix in US letter size paper.
    [OatmealBot.sch]
2018-07-14 Fixed servos, added PWM chip
    [OatmealBot.sch, OatmealBoxMotorController.sch]
2018-07-17 Created symbol for TB6612FNG motor driver. Added first motor driver and hooked it up.
    [OatmealBot.sch]
2018-07-18 Added second motor driver. Got everything hooked up back.
    [OatmealBot.sch, OatmealBoxMotorController.sch]
2018-07-18 Connected I2C, fixed ERC errors
    Connected I2C to the PWM controller.
    Fixed ERC errors.
    [OatmealBot.sch, OatmealBoxMotorController.sch]
2018-07-19 Added caps for the motor drivers
    [OatmealBot.sch, OatmealBoxMotorController.sch]
2018-07-22 Cleaned up, renamed a few things and added all footprints.
    [OatmealBot.sch, OatmealBoxMotorController.sch]
2018-07-22 Fixed the name of the motor controller sheet.
    [OatmealBot.sch, OatmealBotMotorController.sch]
2018-07-22 Started work on the board layout.
    [OatmealBot.kicad_pcb]
2018-07-24 Initial lay out of servo headers and all components.
    [OatmealBot.kicad_pcb, OatmealBot.sch, OatmealBotMotorController.sch]
2018-07-25 Footprint changes and board layout changes
    [OatmealBot.kicad_pcb, OatmealBot.sch, OatmealBotMotorController.sch]
2018-08-01 PCB layout changes
    Move things around to make the high power tracks shorter
    [OatmealBot.kicad_pcb]
2018-08-05 Layout refinement, better power connector
    [OatmealBot.kicad_pcb, OatmealBot.sch, OatmealBotMotorController.sch]
